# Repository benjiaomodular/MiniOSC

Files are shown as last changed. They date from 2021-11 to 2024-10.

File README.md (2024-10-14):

# MiniOSC
[][cc-by-sa]

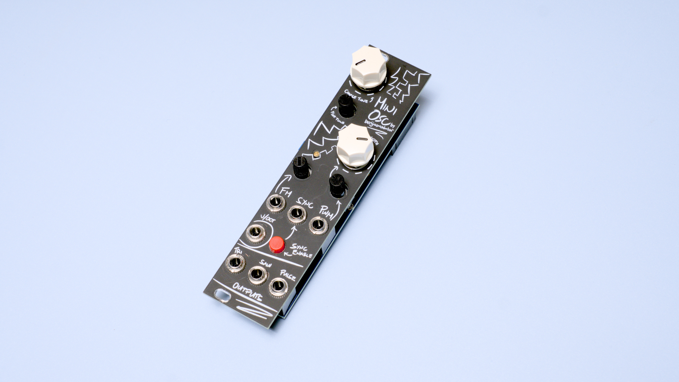
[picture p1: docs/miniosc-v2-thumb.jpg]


## Schematics
**Version 2.1**

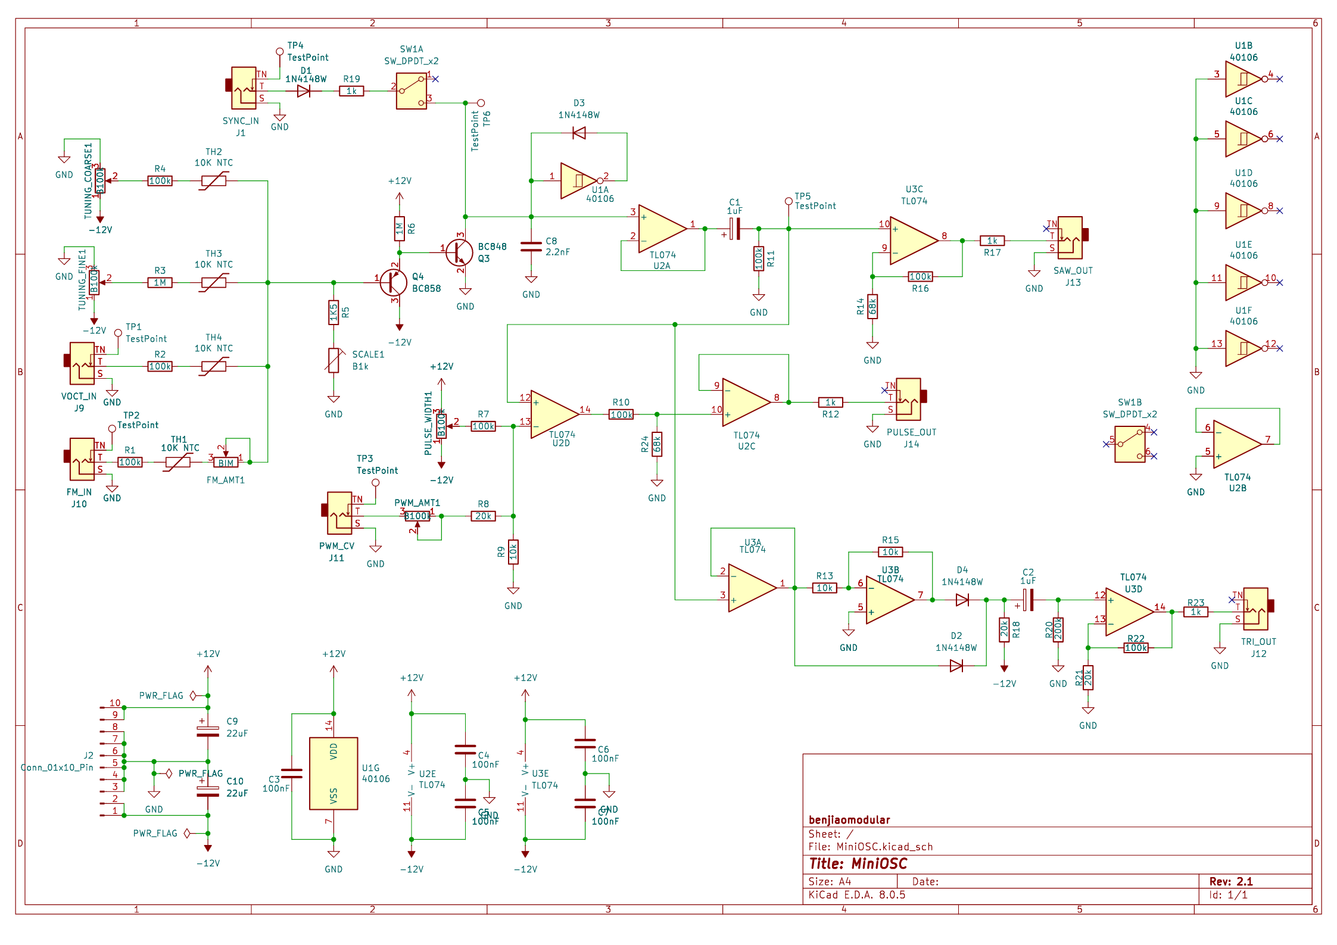
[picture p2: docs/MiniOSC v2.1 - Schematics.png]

More info on my website: 

## PCBs
This project was sponsored by PCBWay. You can order the boards from them directly!
1. [MiniOSC v2.1 - Front panel](https://www.pcbway.com/project/shareproject/_1_of_2_MiniOSC_v2_1_Front_Panel_4b8c5ae8.html) 
2. [MiniOSC v2.1 - Main board](https://www.pcbway.com/project/shareproject/_2_of_2_MiniOSC_v2_1_Main_Board_2ed4e925.html)

You can also download my files from https://github.com/benjiaomodular/MiniOSC/blob/main/fabrication/

## Old versions

**Version 1.1**

DSC03716 resized
More info on my website: https://benjiaomodular.com/post/2021-12-03-volt-per-octave-40106-vco/

## License

This work is licensed under a
[Creative Commons Attribution-ShareAlike 4.0 International License][cc-by-sa].

[][cc-by-sa]

[cc-by-sa]: http://creativecommons.org/licenses/by-sa/4.0/
[cc-by-sa-image]: https://licensebuttons.net/l/by-sa/4.0/88x31.png
[cc-by-sa-shield]: https://img.shields.io/badge/License-CC%20BY--SA%204.0-lightgrey.svg

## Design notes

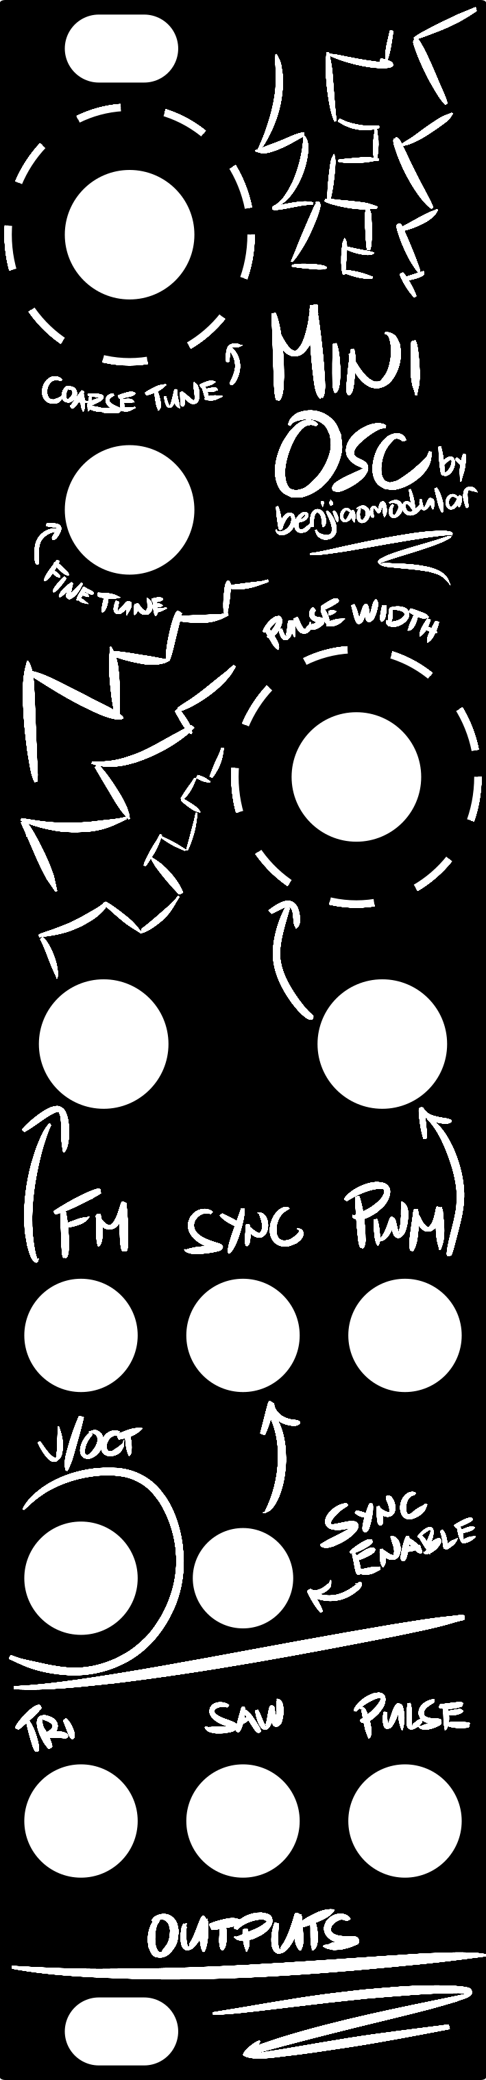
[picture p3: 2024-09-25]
hardware/panel/MiniOSC - Panel with Holes.png

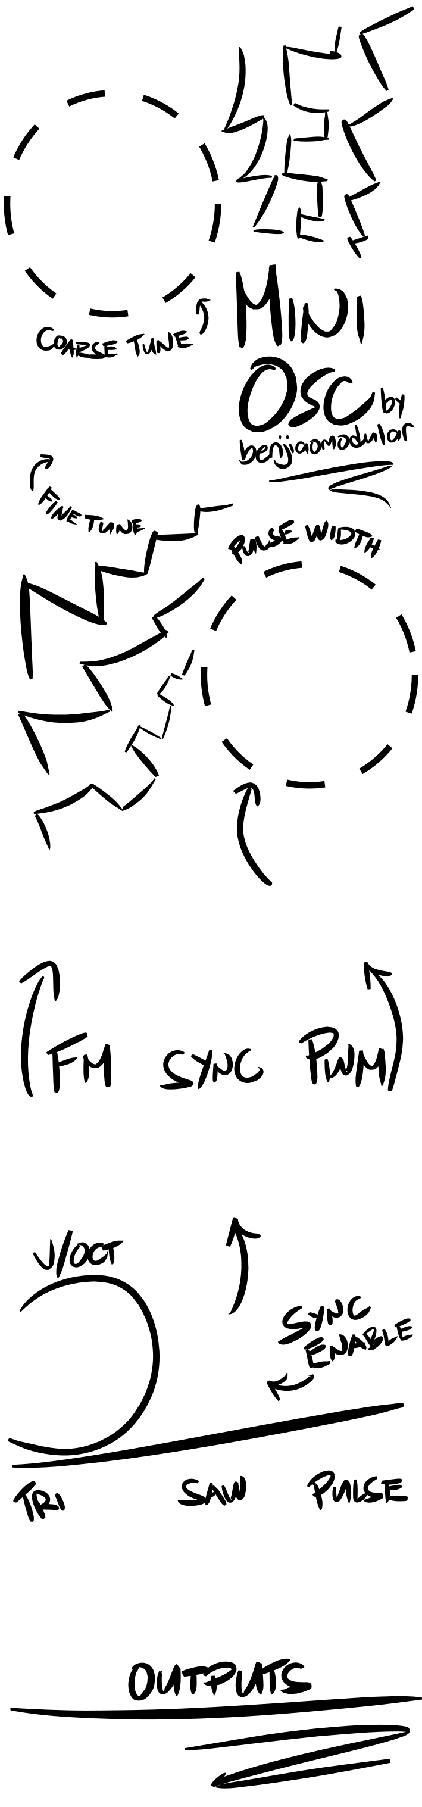
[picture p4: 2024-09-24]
hardware/panel/MiniOSC - Panel.png

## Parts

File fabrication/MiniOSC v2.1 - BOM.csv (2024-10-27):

null | Placed | References | Value | Footprint | URL | Manufacturer | Part # | Quantity
1 | ✓ | C3, C4, C5, C6, C7 | 100nF | C_0805_2012Metric_Pad1.18x1.45mm_HandSolder | https://mou.sr/4ekMsbM | YAGEO | CC0603JRX7R9BB104 | 5
2 | ✓ | C1, C2 | 1uF | C_0805_2012Metric_Pad1.18x1.45mm_HandSolder | https://mou.sr/3XEhBl3 | TAIYO YUDEN | UMK107AB7105KA-T | 2
3 | ✓ | C9, C10 | 22uF | CP_Elec_4x5.8 | https://mou.sr/4ekMqRc | Panasonic | EEE-FT1V220AR | 2
4 | ✓ | C8 | 2.2nF | C_0603_1608Metric_Pad1.08x0.95mm_HandSolder | https://mou.sr/3zee3wG | Vishay / Vitramon | VJ0603Y681KXAAC | 1
5 | ✓ | R1, R2, R4, R7, R10, R11, R16, R22 | 100k | R_0603_1608Metric_Pad0.98x0.95mm_HandSolder | https://mou.sr/4el3qXS | YAGEO | RC0603FR-07100KL | 8
6 | ✓ | R12, R17, R19, R23 | 1k | R_0603_1608Metric_Pad0.98x0.95mm_HandSolder | https://mou.sr/3MKtPCB | YAGEO | RC0603FR-071KL | 4
7 | ✓ | R8, R18, R21 | 20k | R_0603_1608Metric_Pad0.98x0.95mm_HandSolder | https://mou.sr/3z5b9KJ | YAGEO | RC0603FR-0720KL | 3
8 | ✓ | R9, R13, R15 | 10k | R_0603_1608Metric_Pad0.98x0.95mm_HandSolder | https://mou.sr/3MINYsI | YAGEO | AC0603FR-0710KL | 3
9 | ✓ | R3, R6 | 1M | R_0603_1608Metric_Pad0.98x0.95mm_HandSolder | https://mou.sr/3Znalvs | YAGEO | RC0603FR-071ML | 2
10 | ✓ | R14, R24 | 68k | R_0603_1608Metric_Pad0.98x0.95mm_HandSolder | https://mou.sr/3ToI2ZD | YAGEO | RC0603FR-0768KL | 2
11 | ✓ | R5 | 1K5 | R_0603_1608Metric_Pad0.98x0.95mm_HandSolder | https://mou.sr/3zoxpz1 | YAGEO | RC0603FR-071K5L | 1
12 | ✓ | R20 | 200k | R_0603_1608Metric_Pad0.98x0.95mm_HandSolder | https://mou.sr/3XFl5np | Bourns | CR0603-FX-2003ELF | 1
13 | ✓ | D1, D2, D3, D4 | 1N4148W | D_SOD-123 | https://mou.sr/3XEhTbD | Panjit | 1N4148W_R2_00001 | 4
14 | ✓ | U2, U3 | TL074 | SOIC-14_3.9x8.7mm_P1.27mm | https://mou.sr/3z6QVAe | STMicroelectronics | TL074ACDT | 2
15 | ✓ | U1 | 40106 | SOIC-14_3.9x8.7mm_P1.27mm | https://mou.sr/47m5xIo | Texas Instruments | CD40106BM96G4 | 1
16 |  | SW1 | SW_DPDT_x2 | Button_KFC7x7 | https://www.taydaelectronics.com/push-button-switch-dc-30v-0-1a-dpdt-7x7mm.html | DAIER | PB-22E27-ROHS | 1
17 | ✓ | TH1, TH2, TH3, TH4 | 10K NTC | R_0805_2012Metric_Pad1.20x1.40mm_HandSolder | https://mou.sr/4el3hDO | Vishay / BC Components | NTCS0603E3103JLT | 4
18 | ✓ | PULSE_WIDTH1, TUNING_COARSE1 | B100k | Potentiometer_RV09 | https://www.taydaelectronics.com/tayda-100k-ohm-linear-taper-potentiometer-round-shaft-pcb-9mm-6-35-mm.html | Tayda Electronics | RV9312NO-OS15A00-B100K-060 | 2
19 |  | PWM_AMT1, TUNING_FINE1 | B100k | Potentiometer_RV09 | https://www.taydaelectronics.com/100k-ohm-linear-taper-potentiometer-round-knurled-plastic-shaft-pcb-9mm.html | ALPHA | RV09AF-40-20K-B100K | 2
20 |  | FM_AMT1 | B1M | Potentiometer_RV09 | https://www.taydaelectronics.com/1m-ohm-linear-taper-potentiometer-round-knurled-plastic-shaft-pcb-9mm.html | ALPHA | RV09AF-40-20K-B1M | 1
21 | ✓ | Q3 | BC848 | SOT-23 | https://mou.sr/3B2EAO3 | onsemi | BC848ALT1G | 1
22 | ✓ | Q4 | BC858 | SOT-23 | https://mou.sr/3ZkYkq0 | onsemi | BC858CLT3G | 1
23 | ✓ | SCALE1 | B1k | Potentiometer_Bourns_3296W_Vertical | https://www.taydaelectronics.com/1k-ohm-trimmer-potentiometer-cermet-25-turns-3296w.html | ALPHA | 3296W-1-102LF | 1
24 |  | J1 | SYNC_IN | AudioJack_3.5mm | https://www.taydaelectronics.com/pj-3001f-3-5-mm-mono-phone-jack.html | Tayda Electronics | PJ-3001F 3.5mm Mono Phone Jack | 1
25 | ✓ | J2 | Conn_01x10_Pin | Header_IDC2x05_NoArrow |  | XKB Connectivity | X9555WV-2X05-6TV01 | 1
26 |  | J9 | VOCT_IN | AudioJack_3.5mm | https://www.taydaelectronics.com/pj-3001f-3-5-mm-mono-phone-jack.html | Tayda Electronics | PJ-3001F 3.5mm Mono Phone Jack | 1
27 |  | J10 | FM_IN | AudioJack_3.5mm | https://www.taydaelectronics.com/pj-3001f-3-5-mm-mono-phone-jack.html | Tayda Electronics | PJ-3001F 3.5mm Mono Phone Jack | 1
28 |  | J11 | PWM_CV | AudioJack_3.5mm | https://www.taydaelectronics.com/pj-3001f-3-5-mm-mono-phone-jack.html | Tayda Electronics | PJ-3001F 3.5mm Mono Phone Jack | 1
29 |  | J12 | TRI_OUT | AudioJack_3.5mm | https://www.taydaelectronics.com/pj-3001f-3-5-mm-mono-phone-jack.html | Tayda Electronics | PJ-3001F 3.5mm Mono Phone Jack | 1
30 |  | J13 | SAW_OUT | AudioJack_3.5mm | https://www.taydaelectronics.com/pj-3001f-3-5-mm-mono-phone-jack.html | Tayda Electronics | PJ-3001F 3.5mm Mono Phone Jack | 1
31 |  | J14 | PULSE_OUT | AudioJack_3.5mm | https://www.taydaelectronics.com/pj-3001f-3-5-mm-mono-phone-jack.html | Tayda Electronics | PJ-3001F 3.5mm Mono Phone Jack | 1

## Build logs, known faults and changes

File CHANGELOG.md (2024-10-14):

# Versions
#### v2.1 - Fixed initial mistakes
- Resolved Pulse Width and PWM CV pot positions
- Fixed panel hole size for Sync Enable button
- Updated trimpot footprint from 3266Y to 3296w
- Updated value of R21 to 20k to lower amplitude of triangle output a little bit.
- Updated value of R14 to 68k to lower amplitude of saw output a little bit.
- Switched filter caps C9 and C10 footprints to smaller 4mm size. Old ones were unnecessarily too big.

#### v2.0 - Moved to SMD
Issue: Pulse Width and PWM CV pot positions were swapped
Issue: Panel hole for the Sync Enable button was too tight
Issue: Panel hole and footprint position for trim pot was off

#### v1.2. (For verification)
- Update drill holes to follow Doepfer standard placement.
- Exported Gerber files separately per board instead of mousebites.

#### v1.1.
- Issue with mounting holes was fixed. 
- Label sizes increased a bit.

#### v1.0.
- Initial release.
- Mounting holes were too small for M3 screws, fixed by drilling with an M3 bit.

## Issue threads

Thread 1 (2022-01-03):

Use 5mm mousebites

benjiao, 2022-01-03:
JLCPCB requires 5mm wide mousebites. It'll give you a warning if you use anything shorter.

Closed 2022-05-12.

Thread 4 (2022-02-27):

Incorrect panel mount

benjiao, 2022-02-27:
Mounting holes should be 7.5mm from the left edge. Current version should still work for setups without fixed mounting holes on the rails.

Related issue: https://github.com/benjiaomodular/MiniADSR/issues/3

Closed 2022-05-12.

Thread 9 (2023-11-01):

Silkscreen issues

crankery, 2023-11-01:
This is rev 1.1, please close if this has already been addressed.

- R14 has the `100K` label on the incorrect layer (on the back of the board)
- D3's silkscreen is ambiguous, no indication of cathode/anode orientation. The square pad is the only indication
- The TL074 silkscreen is very hard to read being placed on top of the U1 label

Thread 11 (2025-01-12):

40106 v.s. TL074

anno73, 2025-01-12:
As you have one more opamp left (U2B), wouldn't it make sense to dump the 40106 completely and replace it with an opamp based schmitt trigger? Especially as only one schmitt trigger is used from the 40106.
Saves one IC - but introduces some resistors.

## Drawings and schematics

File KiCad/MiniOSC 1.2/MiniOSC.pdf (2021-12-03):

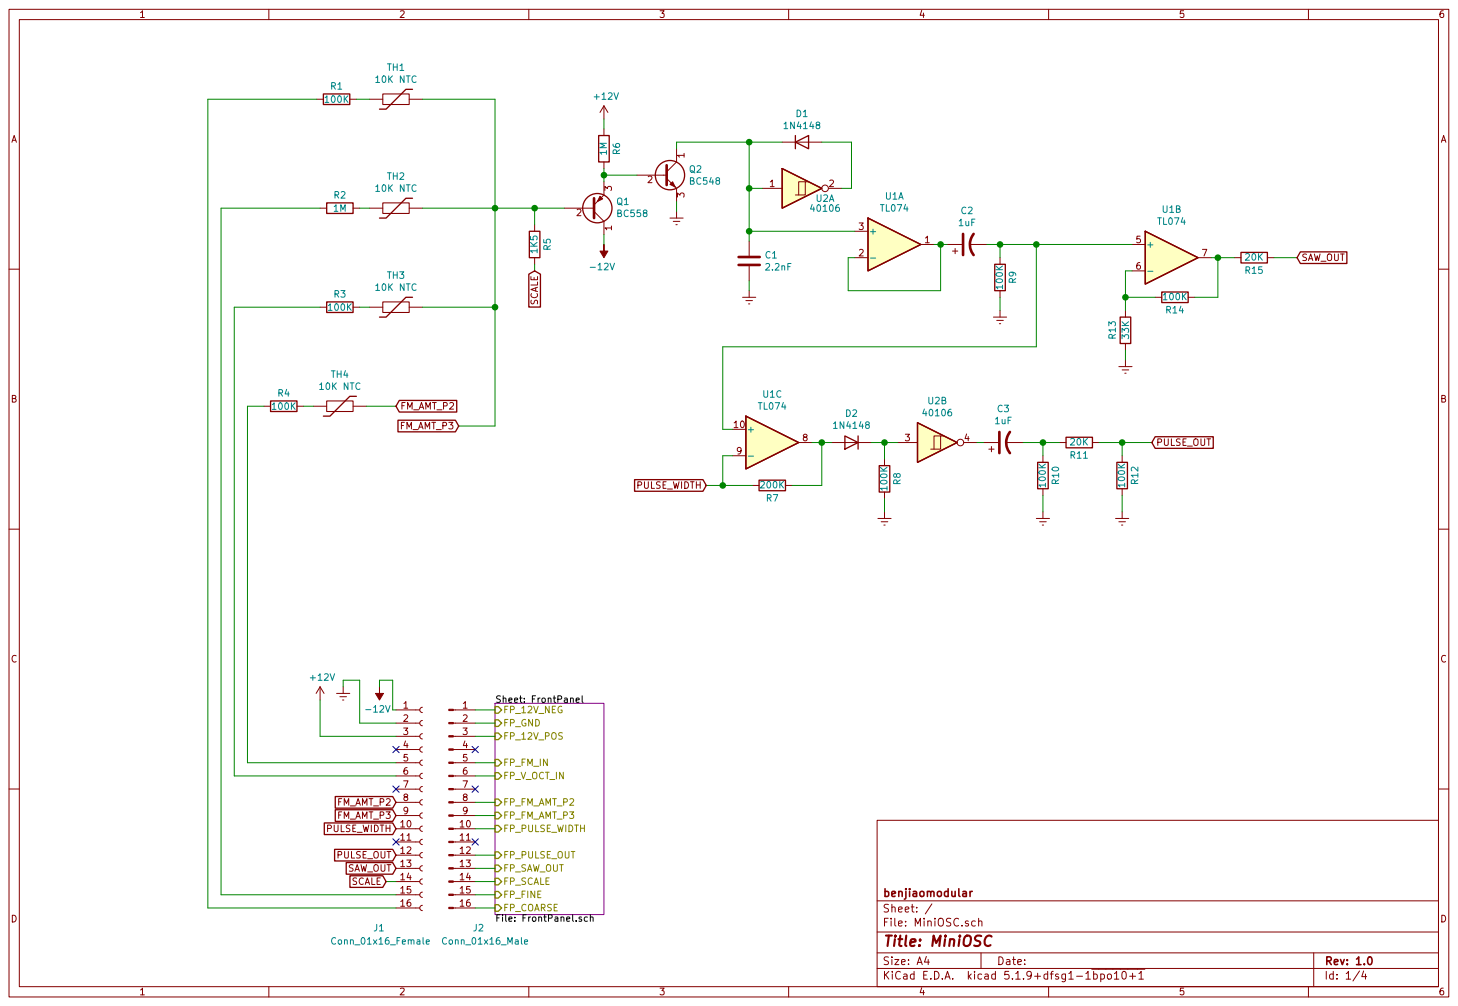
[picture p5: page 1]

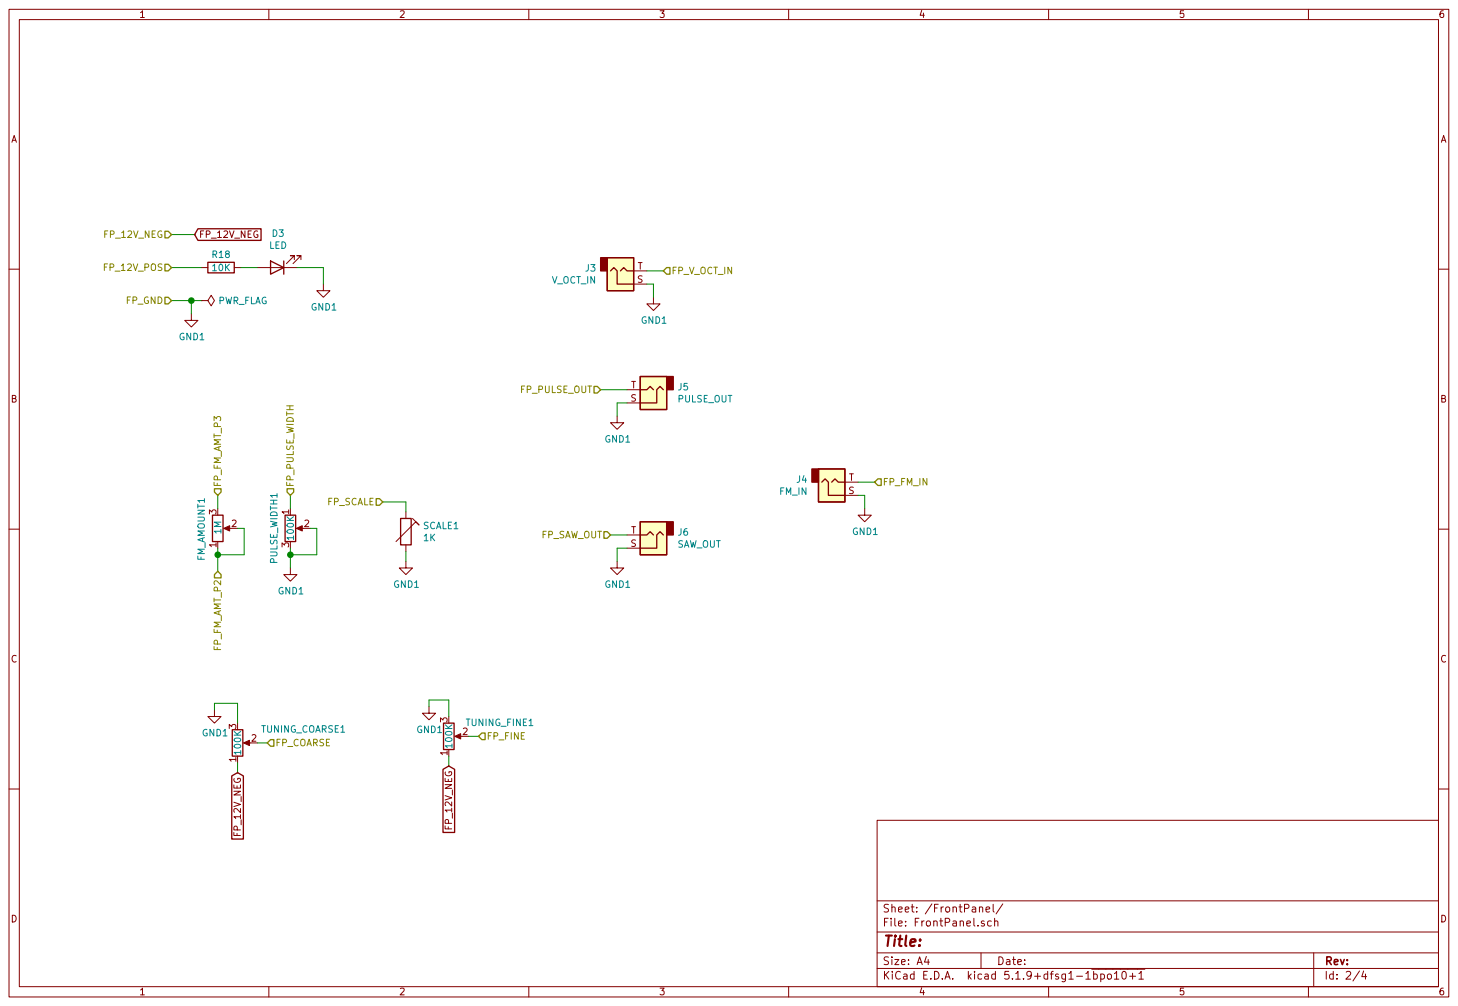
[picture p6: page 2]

Id: 2/4 Title: File: FrontPanel.sch Sheet: /FrontPanel/ S

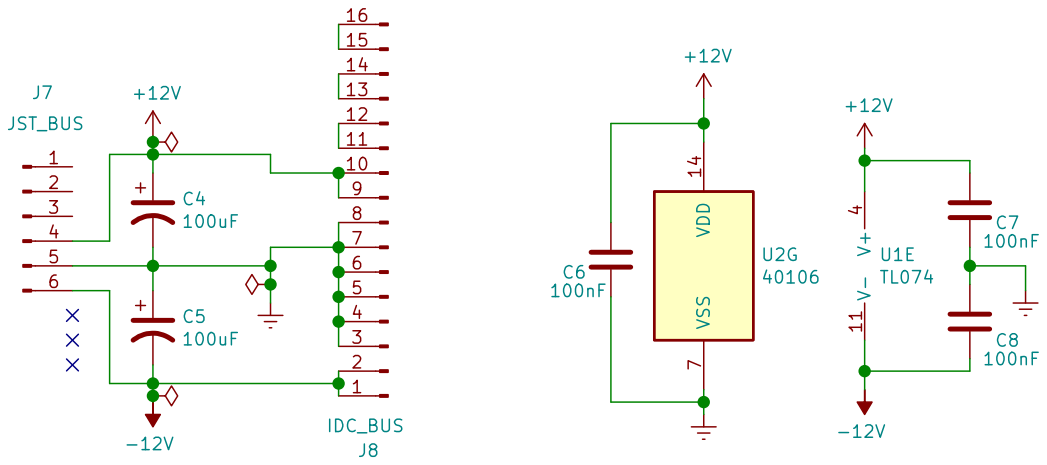
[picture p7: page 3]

Id: 3/4 Title: File: Power.sch Sheet: /Power/

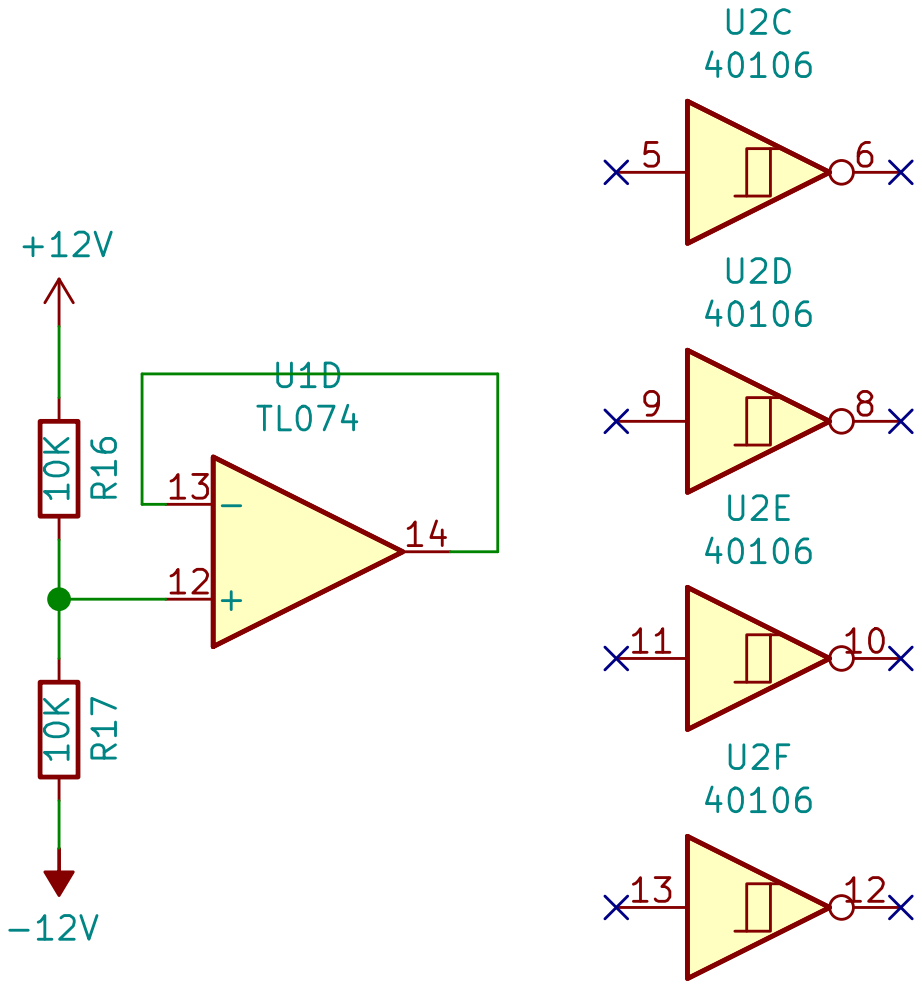
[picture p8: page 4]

Id: 4/4 Title: File: Unused.sch Sheet: /Unused/

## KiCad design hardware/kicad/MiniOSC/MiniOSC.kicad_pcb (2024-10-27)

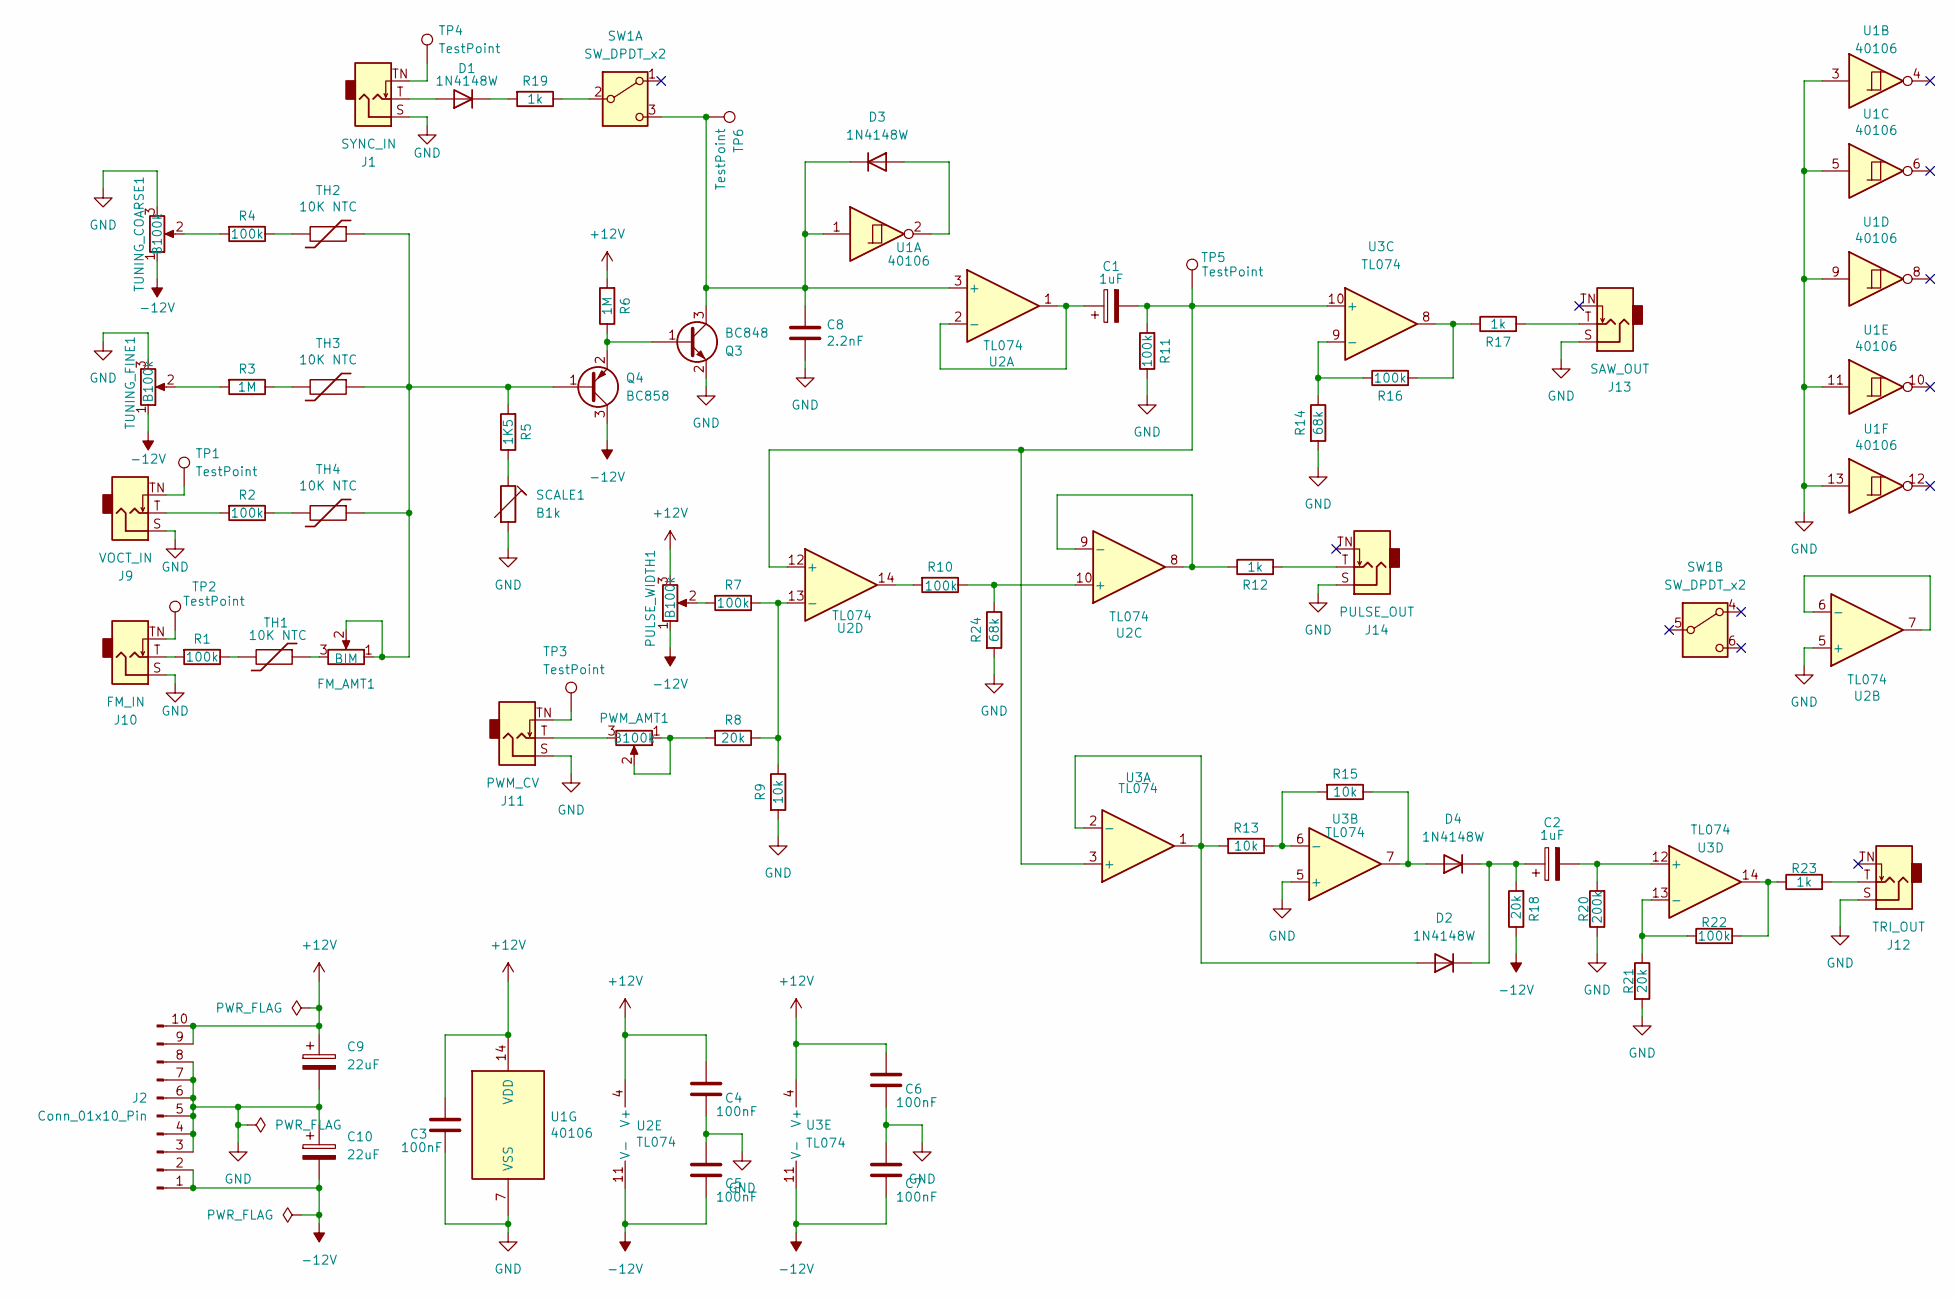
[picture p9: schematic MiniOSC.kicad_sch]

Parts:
C1, C2: 1uF; C_0805_2012Metric_Pad1.18x1.45mm_HandSolder; Part # UMK107AB7105KA-T
C3, C4, C5, C6, C7: 100nF; C_0805_2012Metric_Pad1.18x1.45mm_HandSolder; Part # CC0603JRX7R9BB104
C8: 2.2nF; C_0603_1608Metric_Pad1.08x0.95mm_HandSolder; Part # VJ0603Y681KXAAC
C9, C10: 22uF; CP_Elec_4x5.8; Part # EEE-FT1V220AR
D1, D2, D3, D4: 1N4148W; D_SOD-123; Part # 1N4148W_R2_00001
FM_AMT1: BIM; Potentiometer_RV09; Part # RV09AF-40-20K-B1M
J1: SYNC_IN; AudioJack_3.5mm; Part # PJ-3001F 3.5mm Mono Phone Jack
J2: Conn_01x10_Pin; Header_IDC2x05_NoArrow; Part # X9555WV-2X05-6TV01
J9: VOCT_IN; AudioJack_3.5mm; Part # PJ-3001F 3.5mm Mono Phone Jack
J10: FM_IN; AudioJack_3.5mm; Part # PJ-3001F 3.5mm Mono Phone Jack
J11: PWM_CV; AudioJack_3.5mm; Part # PJ-3001F 3.5mm Mono Phone Jack
J12: TRI_OUT; AudioJack_3.5mm; Part # PJ-3001F 3.5mm Mono Phone Jack
J13: SAW_OUT; AudioJack_3.5mm; Part # PJ-3001F 3.5mm Mono Phone Jack
J14: PULSE_OUT; AudioJack_3.5mm; Part # PJ-3001F 3.5mm Mono Phone Jack
PULSE_WIDTH1: B100k; Potentiometer_RV09; Part # RV9312NO-OS15A00-B100K-060
PWM_AMT1: B100k; Potentiometer_RV09; Part # RV09AF-40-20K-B100K
Q3: BC848; SOT-23; Part # BC848ALT1G
Q4: BC858; SOT-23; Part # BC858CLT3G
R1, R2, R4, R7, R10, R11, R16, R22: 100k; R_0603_1608Metric_Pad0.98x0.95mm_HandSolder; Part # RC0603FR-07100KL
R3, R6: 1M; R_0603_1608Metric_Pad0.98x0.95mm_HandSolder; Part # RC0603FR-071ML
R5: 1K5; R_0603_1608Metric_Pad0.98x0.95mm_HandSolder; Part # RC0603FR-071K5L
R8, R18, R21: 20k; R_0603_1608Metric_Pad0.98x0.95mm_HandSolder; Part # RC0603FR-0720KL
R9, R13, R15: 10k; R_0603_1608Metric_Pad0.98x0.95mm_HandSolder; Part # AC0603FR-0710KL
R12, R17, R19, R23: 1k; R_0603_1608Metric_Pad0.98x0.95mm_HandSolder; Part # RC0603FR-071KL
R14, R24: 68k; R_0603_1608Metric_Pad0.98x0.95mm_HandSolder; Part # RC0603FR-0768KL
R20: 200k; R_0603_1608Metric_Pad0.98x0.95mm_HandSolder; Part # CR0603-FX-2003ELF
SCALE1: B1k; Potentiometer_Bourns_3296W_Vertical; Part # 3296W-1-102LF
SW1: SW_DPDT_x2; Button_KFC7x7; Part # PB-22E27-ROHS
TH1, TH2, TH3, TH4: 10K NTC; R_0805_2012Metric_Pad1.20x1.40mm_HandSolder; Part # NTCS0603E3103JLT
TP1, TP2, TP3, TP4, TP5, TP6: TestPoint; SolderWirePad_1x01_SMD_1x2mm
TUNING_COARSE1: B100k; Potentiometer_RV09; Part # RV9312NO-OS15A00-B100K-060
TUNING_FINE1: B100k; Potentiometer_RV09; Part # RV09AF-40-20K-B100K
U1: 40106; SOIC-14_3.9x8.7mm_P1.27mm; Part # CD40106BM96G4
U2, U3: TL074; SOIC-14_3.9x8.7mm_P1.27mm; Part # TL074ACDT

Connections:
+12V: C3.1, C4.1, C6.1, C9.1, J2.9, J2.10, PULSE_WIDTH1.3, R6.2, U1.14 (VDD), U2.4 (V+), U3.4 (V+)
-12V: C5.2, C7.2, C10.2, J2.1, J2.2, PULSE_WIDTH1.1, Q4.3 (C), R18.1, TUNING_COARSE1.1, TUNING_FINE1.1, U2.11 (V-), U3.11 (V-)
GND: C3.2, C4.2, C5.1, C6.2, C7.1, C8.2, C9.2, C10.1, J1.S, J2.3, J2.4, J2.5, J2.6, J2.7, J2.8, J9.S, J10.S, J11.S, J12.S, J13.S, J14.S, Q3.2 (E), R9.2, R11.1, R14.2, R20.1, R21.2, R24.2, SCALE1.2, TUNING_COARSE1.3, TUNING_FINE1.3, U1.3, U1.5, U1.7 (VSS), U1.9, U1.11, U1.13, U2.5 (+), U3.5 (+)
unnamed: D1.2 (A), J1.T
unnamed: D1.1 (K), R19.2
unnamed: D2.2 (A), R13.2, U3.1, U3.2 (-)
unnamed: C2.1, D2.1 (K), D4.1 (K), R18.2
unnamed: D3.2 (A), U1.2
unnamed: C8.1, D3.1 (K), Q3.3 (C), SW1.3 (C), TP6.1, U1.1, U2.3 (+)
unnamed: D4.2 (A), R15.1, U3.7
unnamed: FM_AMT1.3, TH1.1
unnamed: J1.TN, TP4.1
unnamed: J9.T, R2.2
unnamed: J9.TN, TP1.1
unnamed: J10.T, R1.2
unnamed: J10.TN, TP2.1
unnamed: J11.T, PWM_AMT1.3
unnamed: J11.TN, TP3.1
unnamed: J12.T, R23.2
unnamed: J13.T, R17.2
unnamed: J14.T, R12.2
unnamed: PULSE_WIDTH1.2, R7.2
unnamed: PWM_AMT1.1, PWM_AMT1.2, R8.2
unnamed: Q3.1 (B), Q4.2 (E), R6.1
unnamed: FM_AMT1.1, FM_AMT1.2, Q4.1 (B), R5.2, TH2.1, TH3.1, TH4.1
unnamed: R1.1, TH1.2
unnamed: R2.1, TH4.2
unnamed: R3.1, TH3.2
unnamed: R3.2, TUNING_FINE1.2
unnamed: R4.1, TH2.2
unnamed: R4.2, TUNING_COARSE1.2
unnamed: R5.1, SCALE1.1
unnamed: R10.2, U2.14
unnamed: R16.2, R17.1, U3.8
unnamed: R22.2, R23.1, U3.14
unnamed: R19.1, SW1.2 (B)
unnamed: C1.1, U2.1, U2.2 (-)
unnamed: U2.6 (-), U2.7
unnamed: R10.1, R24.1, U2.10 (+)
unnamed: R12.1, U2.8, U2.9 (-)
unnamed: C1.2, R11.2, TP5.1, U2.12 (+), U3.3 (+), U3.10 (+)
unnamed: R7.1, R8.1, R9.1, U2.13 (-)
unnamed: R13.1, R15.2, U3.6 (-)
unnamed: R14.1, R16.1, U3.9 (-)
unnamed: C2.2, R20.2, U3.12 (+)
unnamed: R21.1, R22.1, U3.13 (-)

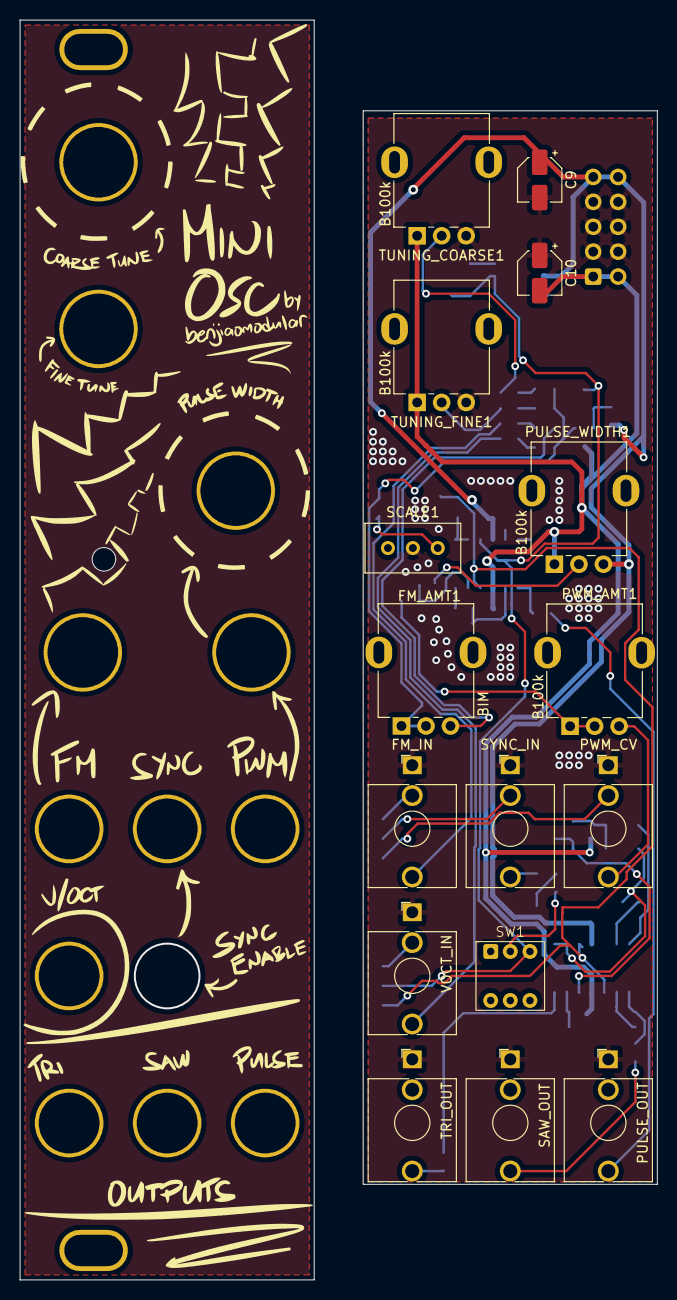
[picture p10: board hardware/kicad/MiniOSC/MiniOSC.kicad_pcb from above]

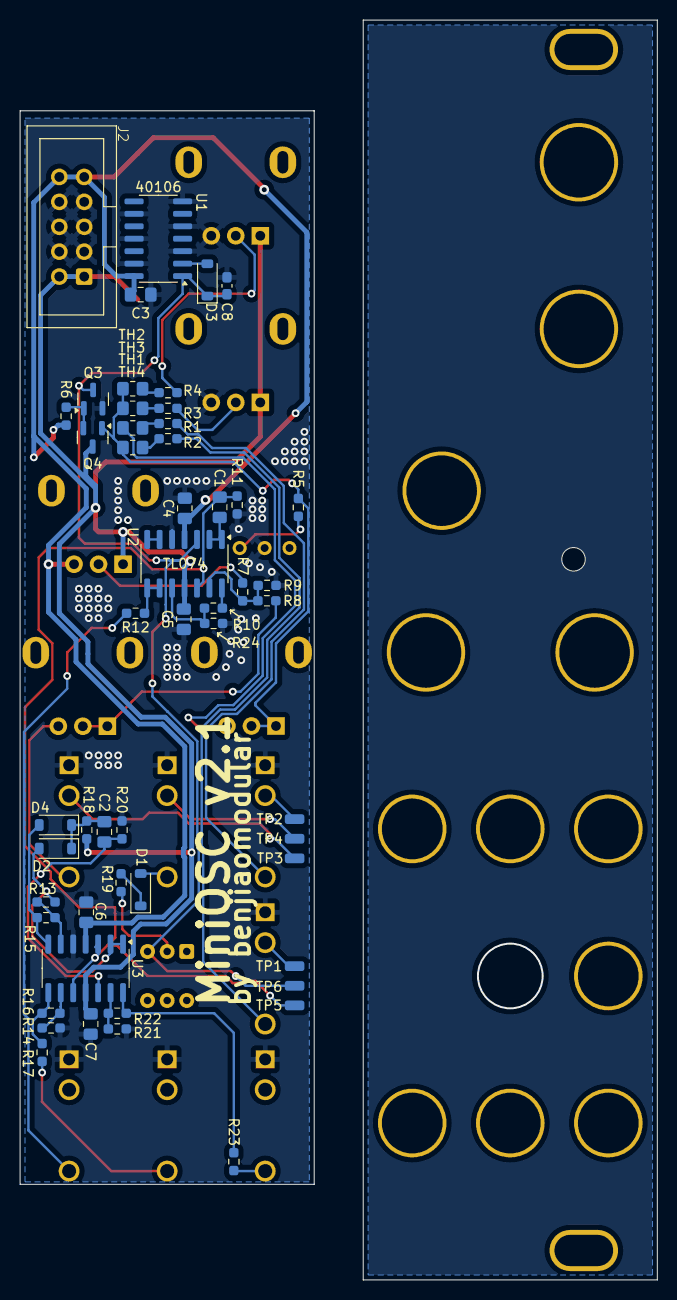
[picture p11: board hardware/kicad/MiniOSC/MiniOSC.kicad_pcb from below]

Board: 2 copper layers, 30.0 x 109.5 mm, 68 parts (52 on the bottom side), 46 nets.

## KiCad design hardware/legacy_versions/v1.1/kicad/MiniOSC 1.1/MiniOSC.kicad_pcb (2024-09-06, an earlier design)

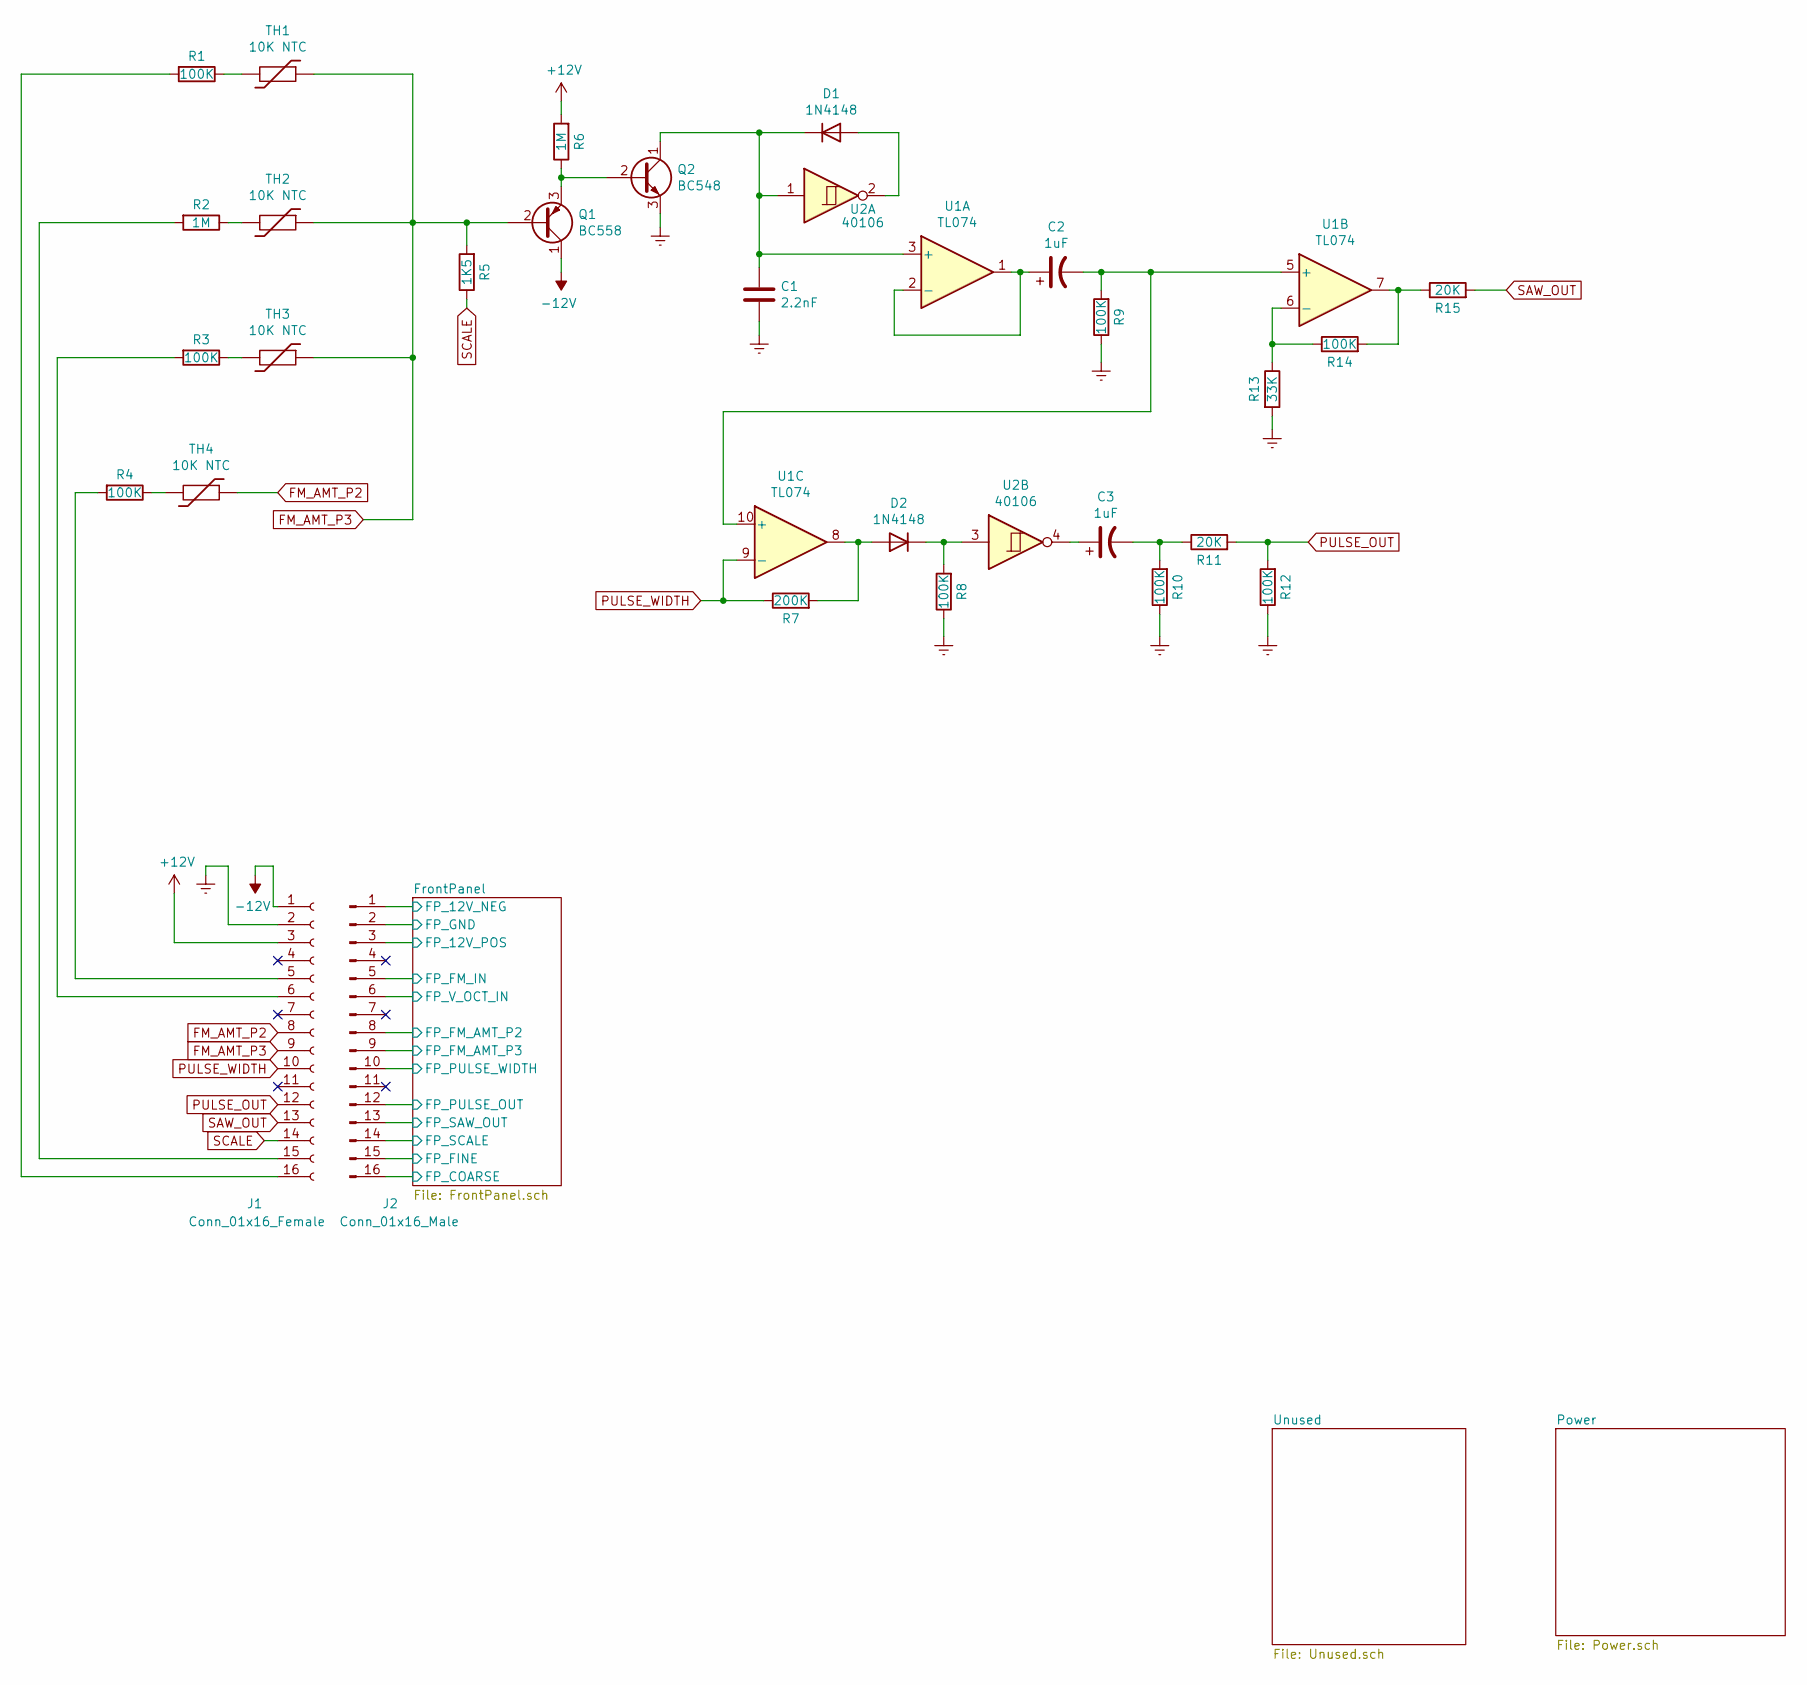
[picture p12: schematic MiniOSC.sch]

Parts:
C1: 2.2nF; C_Rect_L7.2mm_W2.5mm_P5.00mm_FKS2_FKP2_MKS2_MKP2
C2, C3: 1uF; CP_Radial_D5.0mm_P2.50mm
D1, D2: 1N4148; D_DO-35_SOD27_P7.62mm_Horizontal
J1: Conn_01x16_Female; PinHeader_1x16_P2.54mm_Vertical
J2: Conn_01x16_Male; PinHeader_1x16_P2.54mm_Vertical
Q1: BC558; TO-92_Inline
Q2: BC548; TO-92_Inline
R1, R3, R4, R8, R9, R10, R12, R14: 100K; R_Axial_DIN0207_L6.3mm_D2.5mm_P7.62mm_Horizontal
R2, R6: 1M; R_Axial_DIN0207_L6.3mm_D2.5mm_P7.62mm_Horizontal
R5: 1K5; R_Axial_DIN0207_L6.3mm_D2.5mm_P7.62mm_Horizontal
R7: 200K; R_Axial_DIN0207_L6.3mm_D2.5mm_P7.62mm_Horizontal
R11, R15: 20K; R_Axial_DIN0207_L6.3mm_D2.5mm_P7.62mm_Horizontal
R13: 33K; R_Axial_DIN0207_L6.3mm_D2.5mm_P7.62mm_Horizontal
TH1, TH2, TH3, TH4: 10K NTC; C_Disc_D3.8mm_W2.6mm_P2.50mm
U1: TL074; DIP-14_W7.62mm_Socket
U2: 40106; DIP-14_W7.62mm_Socket

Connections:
+12V: J1.3, R6.2; also elsewhere on the board
-12V: J1.1, Q1.1 (C); also elsewhere on the board
/FrontPanel/FP_12V_POS: J2.3; also elsewhere on the board
/FrontPanel/FP_COARSE: J2.16; also elsewhere on the board
/FrontPanel/FP_FINE: J2.15; also elsewhere on the board
/FrontPanel/FP_FM_AMT_P2: J2.8; also elsewhere on the board
/FrontPanel/FP_FM_AMT_P3: J2.9; also elsewhere on the board
/FrontPanel/FP_FM_IN: J2.5; also elsewhere on the board
/FrontPanel/FP_PULSE_OUT: J2.12; also elsewhere on the board
/FrontPanel/FP_PULSE_WIDTH: J2.10; also elsewhere on the board
/FrontPanel/FP_SAW_OUT: J2.13; also elsewhere on the board
/FrontPanel/FP_SCALE: J2.14; also elsewhere on the board
/FrontPanel/FP_V_OCT_IN: J2.6; also elsewhere on the board
Earth: C1.2, J1.2, Q2.3 (E), R8.1, R9.1, R10.1, R12.1, R13.2; also elsewhere on the board
FM_AMT_P2: J1.8, TH4.1
FM_AMT_P3: J1.9, Q1.2 (B), R5.2, TH1.1, TH2.1, TH3.1
FP_12V_NEG: J2.1; also elsewhere on the board
GND1: J2.2; also elsewhere on the board
unnamed: C1.1, D1.1 (K), Q2.1 (C), U1.3 (+), U2.1
unnamed: C2.1, U1.1, U1.2 (-)
unnamed: C2.2, R9.2, U1.5 (+), U1.10 (+)
unnamed: C3.1, U2.4
unnamed: C3.2, R10.2, R11.1
unnamed: D1.2 (A), U2.2
unnamed: D2.1 (K), R8.2, U2.3
unnamed: D2.2 (A), R7.2, U1.8
unnamed: J1.5, R4.2
unnamed: J1.6, R3.2
unnamed: J1.15, R2.2
unnamed: J1.16, R1.2
unnamed: Q1.3 (E), Q2.2 (B), R6.1
unnamed: R1.1, TH1.2
unnamed: R2.1, TH2.2
unnamed: R3.1, TH3.2
unnamed: R4.1, TH4.2
unnamed: R13.1, R14.1, U1.6 (-)
unnamed: R14.2, R15.1, U1.7
PULSE_OUT: J1.12, R11.2, R12.2
PULSE_WIDTH: J1.10, R7.1, U1.9 (-)
SAW_OUT: J1.13, R15.2
SCALE: J1.14, R5.1

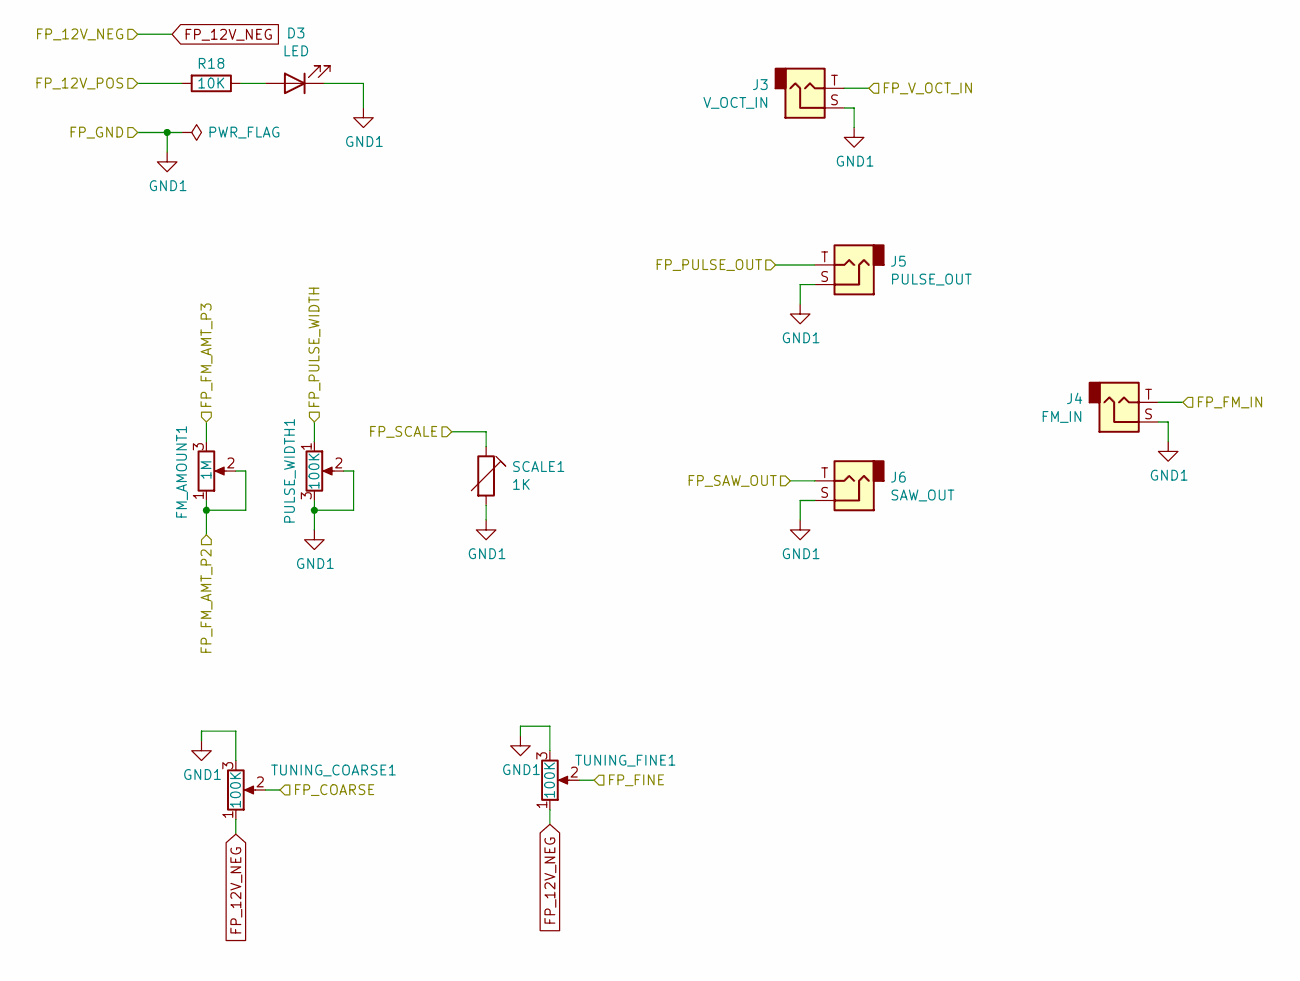
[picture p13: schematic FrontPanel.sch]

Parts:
D3: LED; LED_D3.0mm
FM_AMOUNT1: 1M; Potentiometer_Alpha_RD901F-40-00D_Single_Vertical
J3: V_OCT_IN; Jack_3.5mm_QingPu_WQP-PJ398SM_Vertical_CircularHoles
J4: FM_IN; Jack_3.5mm_QingPu_WQP-PJ398SM_Vertical_CircularHoles
J5: PULSE_OUT; Jack_3.5mm_QingPu_WQP-PJ398SM_Vertical_CircularHoles
J6: SAW_OUT; Jack_3.5mm_QingPu_WQP-PJ398SM_Vertical_CircularHoles
PULSE_WIDTH1: 100K; Potentiometer_Alpha_RD901F-40-00D_Single_Vertical
R18: 10K; R_Axial_DIN0207_L6.3mm_D2.5mm_P7.62mm_Horizontal
SCALE1: 1K; Potentiometer_Bourns_3266Y_Vertical
TUNING_COARSE1: 100K; Potentiometer_Alpha_RD901F-40-00D_Single_Vertical
TUNING_FINE1: 100K; Potentiometer_Alpha_RD901F-40-00D_Single_Vertical

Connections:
/FrontPanel/FP_12V_POS: R18.2; also elsewhere on the board
/FrontPanel/FP_COARSE: TUNING_COARSE1.2; also elsewhere on the board
/FrontPanel/FP_FINE: TUNING_FINE1.2; also elsewhere on the board
/FrontPanel/FP_FM_AMT_P2: FM_AMOUNT1.1, FM_AMOUNT1.2; also elsewhere on the board
/FrontPanel/FP_FM_AMT_P3: FM_AMOUNT1.3; also elsewhere on the board
/FrontPanel/FP_FM_IN: J4.T; also elsewhere on the board
/FrontPanel/FP_PULSE_OUT: J5.T; also elsewhere on the board
/FrontPanel/FP_PULSE_WIDTH: PULSE_WIDTH1.1; also elsewhere on the board
/FrontPanel/FP_SAW_OUT: J6.T; also elsewhere on the board
/FrontPanel/FP_SCALE: SCALE1.1; also elsewhere on the board
/FrontPanel/FP_V_OCT_IN: J3.T; also elsewhere on the board
FP_12V_NEG: TUNING_COARSE1.1, TUNING_FINE1.1; also elsewhere on the board
GND1: D3.1 (K), J3.S, J4.S, J5.S, J6.S, PULSE_WIDTH1.2, PULSE_WIDTH1.3, SCALE1.2, TUNING_COARSE1.3, TUNING_FINE1.3; also elsewhere on the board
unnamed: D3.2 (A), R18.1

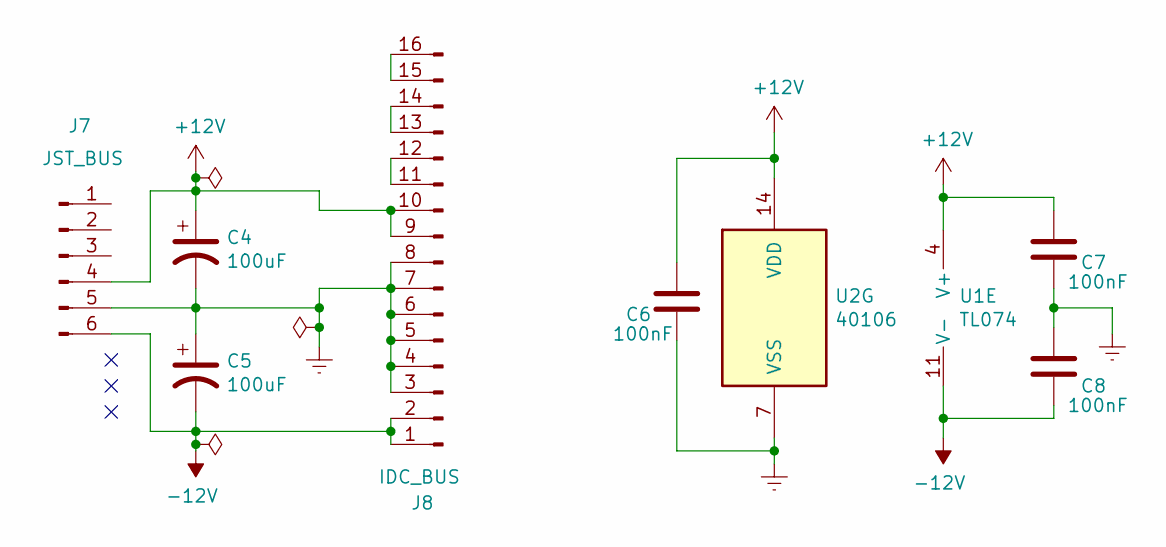
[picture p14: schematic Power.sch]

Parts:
C4, C5: 100uF; CP_Radial_D5.0mm_P2.50mm
C6, C7, C8: 100nF; C_Rect_L7.2mm_W2.5mm_P5.00mm_FKS2_FKP2_MKS2_MKP2
J7: JST_BUS; JST_XH_B6B-XH-A_1x06_P2.50mm_Vertical
J8: IDC_BUS; IDC-Header_2x08_P2.54mm_Vertical
U1: TL074; DIP-14_W7.62mm_Socket
U2: 40106; DIP-14_W7.62mm_Socket

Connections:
+12V: C4.1, C6.1, C7.1, J7.4, J8.9, J8.10, U1.4 (V+), U2.14 (VDD); also elsewhere on the board
-12V: C5.2, C8.2, J7.6, J8.1, J8.2, U1.11 (V-); also elsewhere on the board
Earth: C4.2, C5.1, C6.2, C7.2, C8.1, J7.5, J8.3, J8.4, J8.5, J8.6, J8.7, J8.8, U2.7 (VSS); also elsewhere on the board
unnamed: J8.11, J8.12
unnamed: J8.13, J8.14
unnamed: J8.15, J8.16

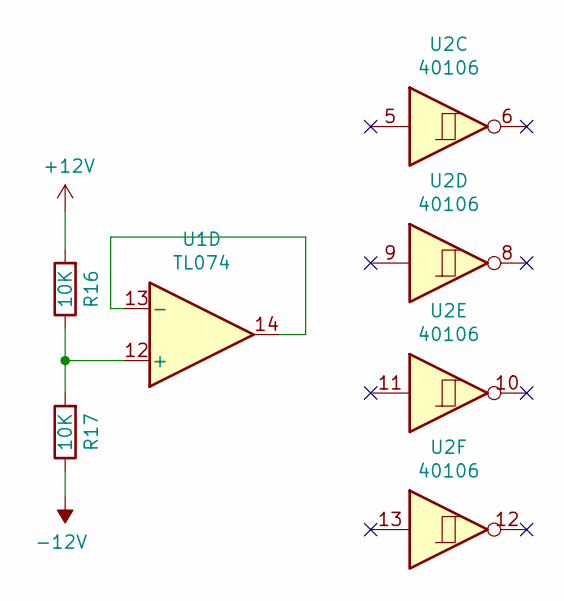
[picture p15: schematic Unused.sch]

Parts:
R16, R17: 10K; R_Axial_DIN0207_L6.3mm_D2.5mm_P7.62mm_Horizontal
U1: TL074; DIP-14_W7.62mm_Socket
U2: 40106

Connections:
+12V: R16.2; also elsewhere on the board
-12V: R17.1; also elsewhere on the board
unnamed: R16.1, R17.2, U1.12 (+)
unnamed: U1.13 (-), U1.14

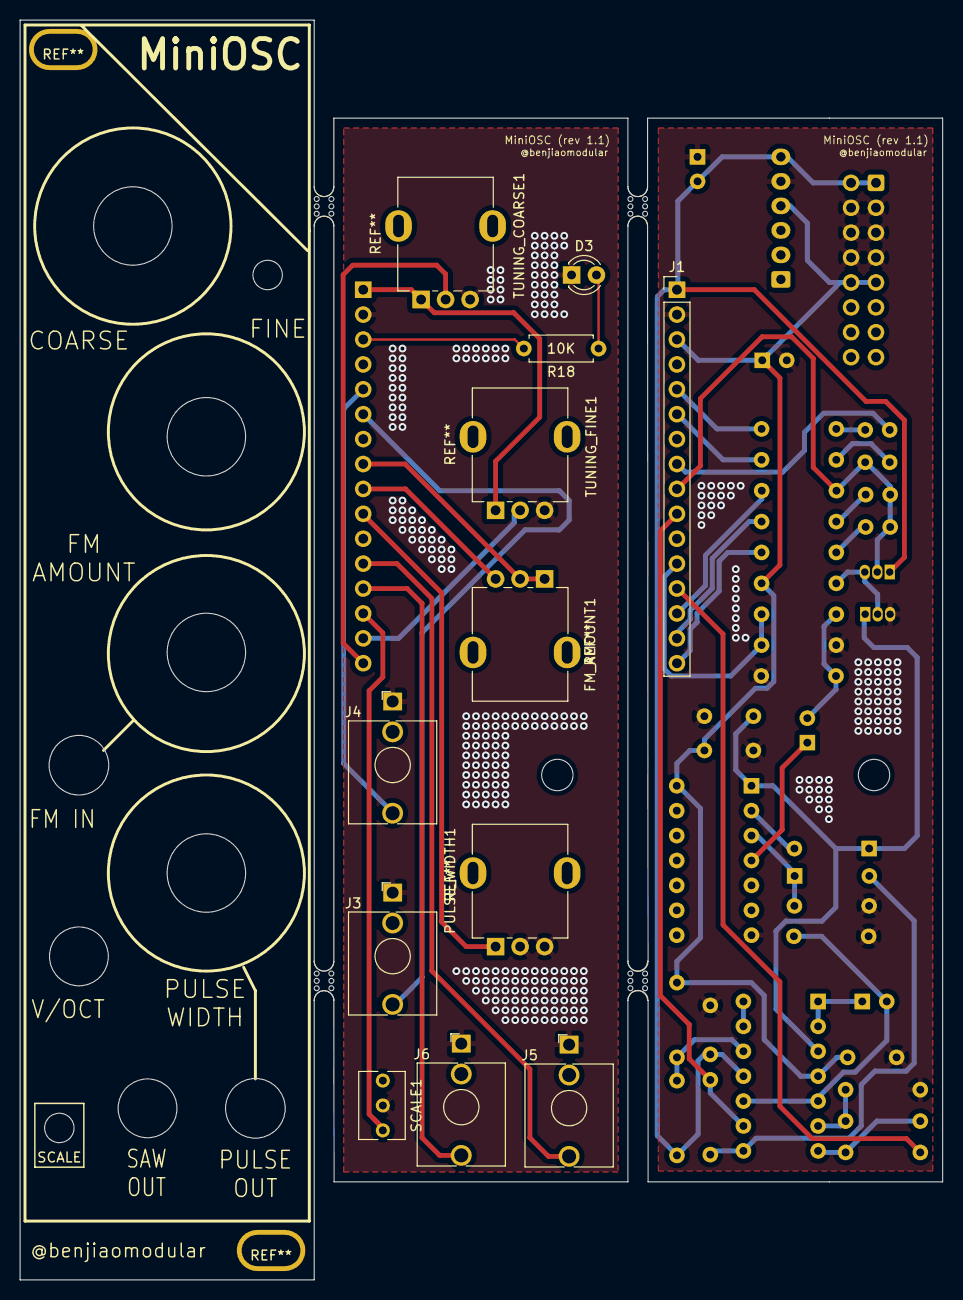
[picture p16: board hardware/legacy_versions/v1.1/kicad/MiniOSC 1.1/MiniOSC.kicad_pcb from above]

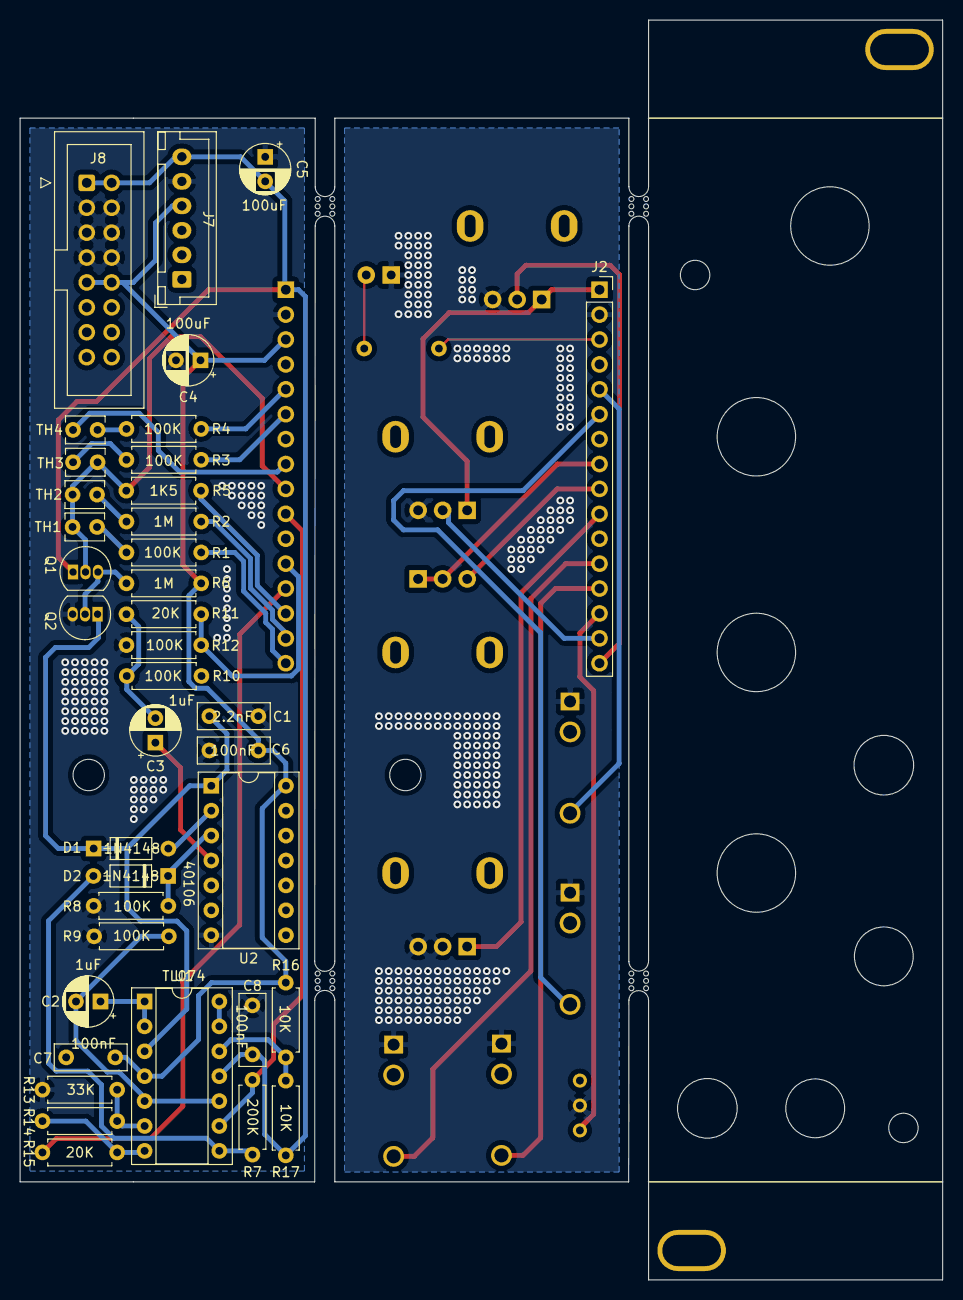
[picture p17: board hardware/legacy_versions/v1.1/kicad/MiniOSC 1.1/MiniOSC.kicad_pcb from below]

Board: 2 copper layers, 94.1 x 128.5 mm, 54 parts (38 on the bottom side), 47 nets.

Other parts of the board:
mouse-bite-2mm-slot, mouse-bite-2mm-slot#2, mouse-bite-2mm-slot#3, mouse-bite-2mm-slot#4: VAL**; mouse-bite-2mm-slot

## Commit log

2021-11-08 Added gerber files
    [MiniOSC-B_Cu.gbr, MiniOSC-B_Mask.gbr, MiniOSC-B_Paste.gbr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]
2021-11-08 reorganized files
    [FrontPanel.sch, MiniOSC.kicad_pcb, MiniOSC.sch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]
2021-12-03 Added rev 1.1
    [FrontPanel.sch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]
2021-12-03 Added BOM files
    [MiniOSC.csv]
2021-12-04 Rename MiniOSC.csv to MiniOSC - BOM.csv
    [MiniOSC - BOM.csv]
2021-12-22 Added simplified schem
    [FrontPanel.sch, MiniOSC.csv, MiniOSC.kicad_pcb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]
2022-01-05 Added fist 1.2 commit
    [FrontPanel.sch, MiniOSC.csv, MiniOSC.kicad_pcb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]
2022-01-07 Transfered labels to solder mask
    [MiniOSC.kicad_pcb]
2022-01-17 Updated labels
    [MiniOSC.kicad_pcb]
2022-05-12 Added v1.2
    [MiniOSC - Control.kicad_pcb, MiniOSC - Front.kicad_pcb, MiniOSC - Main.kicad_pcb]
2022-08-05 Added updated build files for 1.2
    [MiniOSC - Main - BROKEN.kicad_pcb, MiniOSC.kicad_pcb]
2024-04-12 added new branch for v2
    [FrontPanel.kicad_sch, MiniOSC - Control.kicad_pcb, MiniOSC - Front.kicad_pcb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]
2024-09-06 updated symbols and grid to kicad 8
    [MiniOSC.kicad_sch]
2024-09-06 Reorganized files. Updated license to CC-BY-SA
    [FrontPanel.kicad_sch, FrontPanel.sch, MiniOSC - BOM.csv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]
2024-09-11 v2.0 PCB
    [MiniOSC v2.0 - Main.kicad_pcb, MiniOSC v2.0 - Panel.kicad_pcb, MiniOSC.kicad_sch]
2024-09-24 Added v2.1
    [FrontPanel.kicad_sch, MiniOSC v2.0 - Main.kicad_pcb, MiniOSC v2.0 - Panel.kicad_pcb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]
2024-09-25 Added fab files for v2.1
    [MiniOSC.kicad_pcb]
2024-09-25 Updated R21 value
    [MiniOSC.kicad_pcb, MiniOSC.kicad_sch]
2024-09-28 Removed reference label on frontpanel
    [MiniOSC.kicad_pcb]
2024-09-29 Updated changelog
    [MiniOSC.kicad_sch]
2024-10-07 Fixed typo on R14 value
    [MiniOSC.kicad_pcb, MiniOSC.kicad_sch]
2024-10-11 Added manufacture parts numbers to BOM
    [MiniOSC v2.1 - BOM.csv, MiniOSC.kicad_pcb, MiniOSC.kicad_sch]
2024-10-14 Added links to PCBWay, updated bom
    [MiniOSC.csv, MiniOSC.kicad_pcb, MiniOSC.kicad_sch]
2024-10-14 updated bom
    [MiniOSC v2.1 - BOM.csv]
2024-10-27 Fixed v2.1 BOM
    [MiniOSC v2.1 - BOM.csv, MiniOSC.kicad_pcb, MiniOSC.kicad_sch]

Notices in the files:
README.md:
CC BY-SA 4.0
